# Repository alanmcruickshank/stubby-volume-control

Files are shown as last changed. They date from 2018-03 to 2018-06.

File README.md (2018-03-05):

# stubby-volume-control
A distinctly over engineered USB volume control designed in OpenSCAD and programmed using Arduino

## Contents
- [Design](/scad/design.md)
- [Programming](/cpp/programming.md)
- [Assembly](/docs/assembly.md)

## TODO

- Add all the scad files and some explanation of what they do (a branch for the original version first and then a dev branch for the new version)
- Add a full set of stl files and the tag that as a *release* before changing them all.
- Add some docs around print settings for best results, especially for the geared components. i.e. RAFTS!

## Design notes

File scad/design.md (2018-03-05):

# Design

There are a couple of physical design iterations:

- [_Alpha_](/scad/alpha.md) - the first iteration
- [_Beta_](/scad/beta.md) - a stubby incomplete iteration

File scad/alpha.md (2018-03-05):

# Alpha Design

This design was the first and was created iteratively to get *something that worked*.

It incorporates all the main components that the design requires, but is in no way *optimsed*.

## Important points

- Sanding the interface layers with a really fine grain sandpaper helps for really smooth functionality
- Print the geared components with a raft so that we don't get wierd edge effects which affect binding.

## Pictures

### Complete
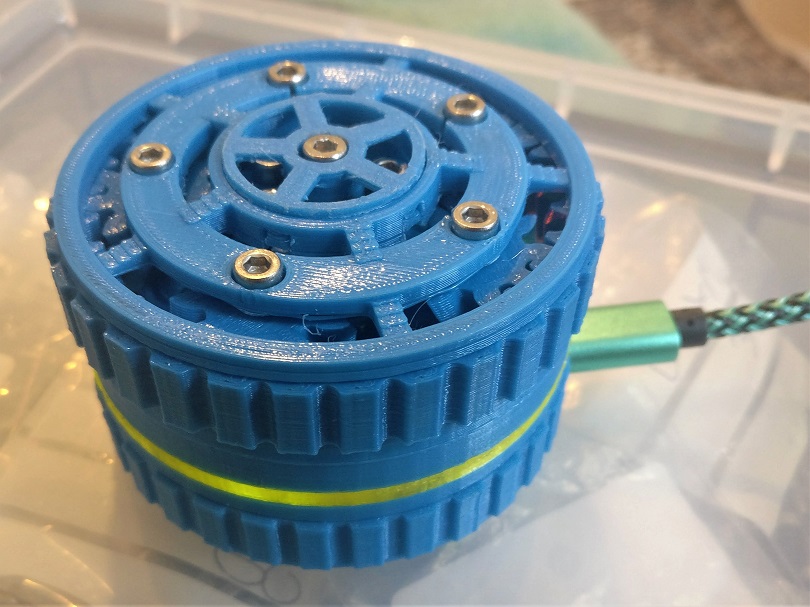
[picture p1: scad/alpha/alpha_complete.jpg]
the complete alpha design


### Upper
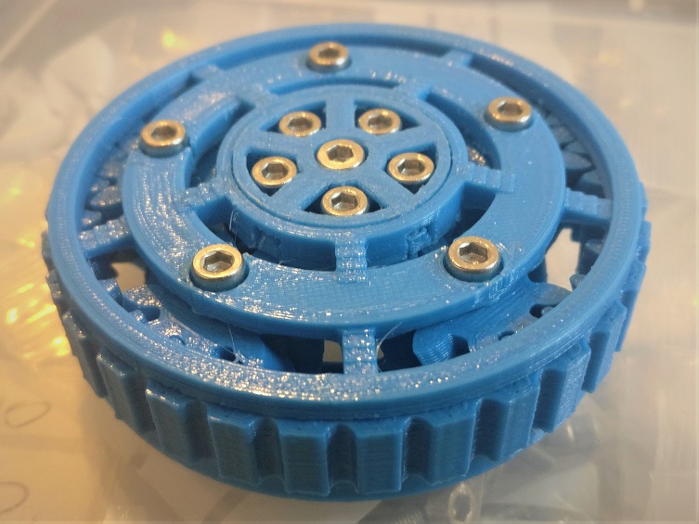
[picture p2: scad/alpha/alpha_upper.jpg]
the upper half of the alpha design


### Lower
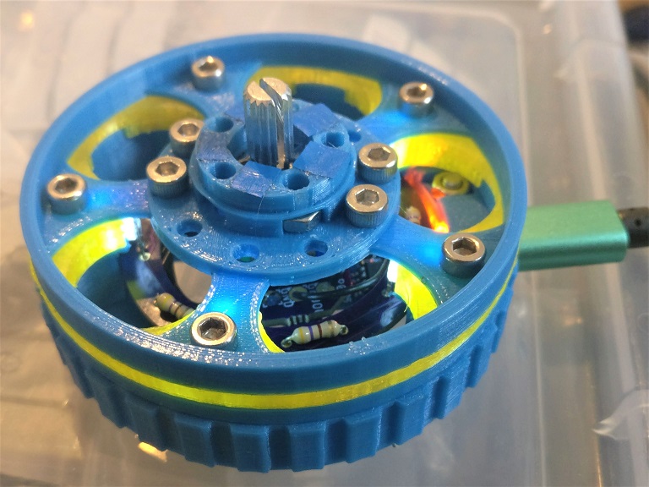
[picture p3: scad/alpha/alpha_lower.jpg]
the lower half of the alpha design


## Good points:

- Design can be assembled as two independant assemblies. The upper **gearbox assembly** and the lower **electronics assembly**. The two are then joined by the five longer central screws.
- The design of the undercarriage is really nice.
- The LED ring works well, although it should probably be centered in the next revision.
- The tolerances work well, and runs very smoothly with only a little post processing. Rafts of the geared components was the right route, and nice thick ones even though this leads to difficulty removing them.
- The height tolerance above the encoder button can be really easily tweeked using tape attached to the top of the central inner encoder mount.

## Bad points:

- It's quite tall! Perhaps just a bit stumpy, and the lower design could be executed better.
- The nuts which join to the longer central joining screws can easily slide out of place. Perhaps an interference fit or some geometry to capture them might be more appropriate for the next design.
- In practice the gearing is actually too low. You have to turn the knob quite a long way for the relevant increase in volume
- You can't just put your finger on the upper rim as that's integrated with the planet gears and not the ring gear, future versions should have the whole top corner be the interface point for a users finger. this should be linked to the external knurling.
- Designing the geared parts with either bevels or chamfers to make it so rafts aren't necessary would make printing much easier.
- The planetary gear carriers (both upper and lower) don't hold the screws very nicely, a thicker lower would hold the nuts better. Ideally printed in such a way that the hexagonal holders are on the upper side to ease printing.
- It's not **obviously** geared - linked to the gear ratio - perhaps a design where the planets are fixed, the outer rign moves and the center turns the encoder could work well. Could also make construction easier. Ideally we need to find a way of statically holding the upper and lower sides of the planet gears for stiffness. It could also mean an off centre encoder??? That could be very cool. An asymmetric planetary system could be fun.
- We've got the arduino interface for all of the multimedia keys. Mute & skip would be useful buttons to also have. Could implement using microswitches, or even better - 3d print a switch??!
- It's quite light, and so doesn't grip very well on the table. Perhaps some legit bearings would make it more weighty.

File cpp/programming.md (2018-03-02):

# Arduino Files

The design uses the [digistump](http://digistump.com/wiki/digispark), although the micro usb version of the standard digistump as [available on aliexpress](https://www.aliexpress.com/item/Mini-ATTINY85-Micro-USB-Development-Board-for-Digispark-Kickstarter/32658933669.html). For this to work in the Arduino environment you need:

- The local Arduino IDE - from [arduino.cc](https://www.arduino.cc/en/Main/Software)
- The relevant digispark drivers for the arduino IDE - instructions [here](http://digistump.com/wiki/digispark/tutorials/connecting).

The USB driver uses (or at least will use) an altered version of the Digispark Keyboard addon, which is part of the [DigistumpArduino library](https://github.com/digistump/DigistumpArduino). The details of how to emulate multimedia keys are inspired by the work done by Adafruit on their [Trinket library](https://github.com/adafruit/Adafruit-Trinket-USB) (most notable the HIDCombo library).

## Loading the firmware

The digistump is programmed directly through the Arduino interface via usb. No additional functionality required. Press *Upload* in the arduino IDE with the right kind of board selected and it should just work. After loading the firmare you may need to unlplug and then reconnect the volume control before it acts as a control properly.

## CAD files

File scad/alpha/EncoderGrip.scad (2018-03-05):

//$fa = 6;
//$fs = 0.4;

encoder_grip();

module encoder_grip(){
    union(){
        difference(){
            union() {
                cylinder(d=10, h=11.5);
            }
            
            // grip the encoder
            cylinder(d=6.4, h=8);
            
            // chamfer for encoder
            cylinder(d1=8, d2=6.45, h=2);
            
            // screw hole
            cylinder(d=3.3, h=14);
            
            // key way
            translate([2.5,-6,11]) cube([12,12,12]);
            translate([-2.5-12,-6,11]) cube([12,12,12]);
            
            // captive nut
            translate([0,0,9]) cube([12,5.5,2.8], center=true);
            translate([0,0,9.5]) cube([3.3,5.5,2.5], center=true);
            
        }

        // encoder keyway
        translate([0,0,3.8]) cube([9,0.6,7.6], center=true);
    }
}

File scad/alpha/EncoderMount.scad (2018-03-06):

$fa = 6;
$fs = 0.4;

// distance of bottom of stator to bottom of grip = 10mm
// encoder fits into grip by 7.6mm

// => 17.6mm of the encoder is above the base of this

// top of encoder is 20mm from bottom of thread

// therefore thickness of 2.4

// thread is M7



difference() {
    union () {
        cylinder(d=34, h=2);
        // higher central mount
        cylinder(d=14, h=3.2);
    }
    
    cylinder(d=7.2, h=8);
    translate([0,0,1.4]) cylinder(d=9, h=8);
    
    //translate([0,-5,1.5]) cube([7, 10, 3], center=true);
    
    for (i=[0:9]) {
        rotate([0,0,(i*36) - 18]) translate([8,0,0]) cylinder(h=8, d=3.4);
    }
    
    for (i=[0,1,5,6]) {
        rotate([0,0,(i*36) - 18]) translate([-14,0,0]) cylinder(h=4, d=3.4);
        rotate([0,0,(i*36) - 18]) translate([-14,0,1]) rotate([0,0,90]) cylinder(d=7, h=4, $fn=6);
        // and again just to cut corners
        rotate([0,0,(i*36) - 18]) translate([-16,0,1]) rotate([0,0,90]) cylinder(d=7, h=4, $fn=6);
    }
    
    // cut the shape
    translate([-40,7,0]) cube([80,10,4]);
    mirror([0,1,0]) translate([-40,7,0]) cube([80,10,4]);
    
}

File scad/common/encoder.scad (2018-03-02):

// Standard encoder dimensions
$fa = 6;
$fs = 0.4;

translate([0,60,0]) encoder_and_board();

translate([60,60,0]) encoder();

translate([-60,60,0]) encoder_board();

module encoder_and_board(){
    union(){
        encoder();
        translate([0,0,-7-3.8]) encoder_board(); 
    } 
}

module encoder_board(){
    translate([-14.2,-9.7,0]) cube([28.4,19.4,3.8]);    
}

module encoder(){
    difference(){
        union(){
            cylinder(d=7, h=7);
            cylinder(d=4, h=16);
            translate([0,0,10]) cylinder(d=6, h=10);
            translate([-6,-6,-7]) cube([12,12,7]);
        }
        // Keyway slot
        translate([0,0,20-5.5]) cube([1,12,11], center=true);  
    }
}

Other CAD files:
scad/alphaAssembly.scad
scad/alpha/BasePlate.scad
scad/alpha/CentreButton.scad
scad/alpha/ElectroHousing.scad
scad/alpha/GearCarrier.scad
scad/alpha/Gears.scad
scad/alpha/LightRing.scad
scad/alpha/LightRingSpacer.scad
scad/alpha/UnderCarrier.scad
scad/alpha/UnderStator.scad
scad/common/fixings.scad

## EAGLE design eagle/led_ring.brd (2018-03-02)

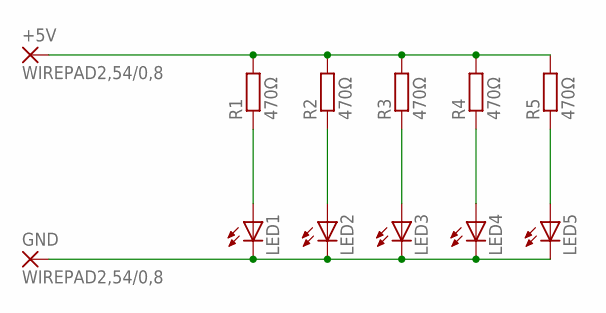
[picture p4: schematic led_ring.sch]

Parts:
+5V: WIREPAD2,54/0,8; 2,54/0,8
GND: WIREPAD2,54/0,8; 2,54/0,8
LED1, LED2, LED3, LED4, LED5: LED5MM
R1, R2, R3, R4, R5: 470Ω; 0204/7

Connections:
unnamed: LED1.A, R1.1
unnamed: LED2.A, R2.1
unnamed: LED3.A, R3.1
unnamed: LED4.A, R4.1
unnamed: LED5.A, R5.1
unnamed: +5V.1, R1.2, R2.2, R3.2, R4.2, R5.2
unnamed: GND.1, LED1.K (C), LED2.K (C), LED3.K (C), LED4.K (C), LED5.K (C)

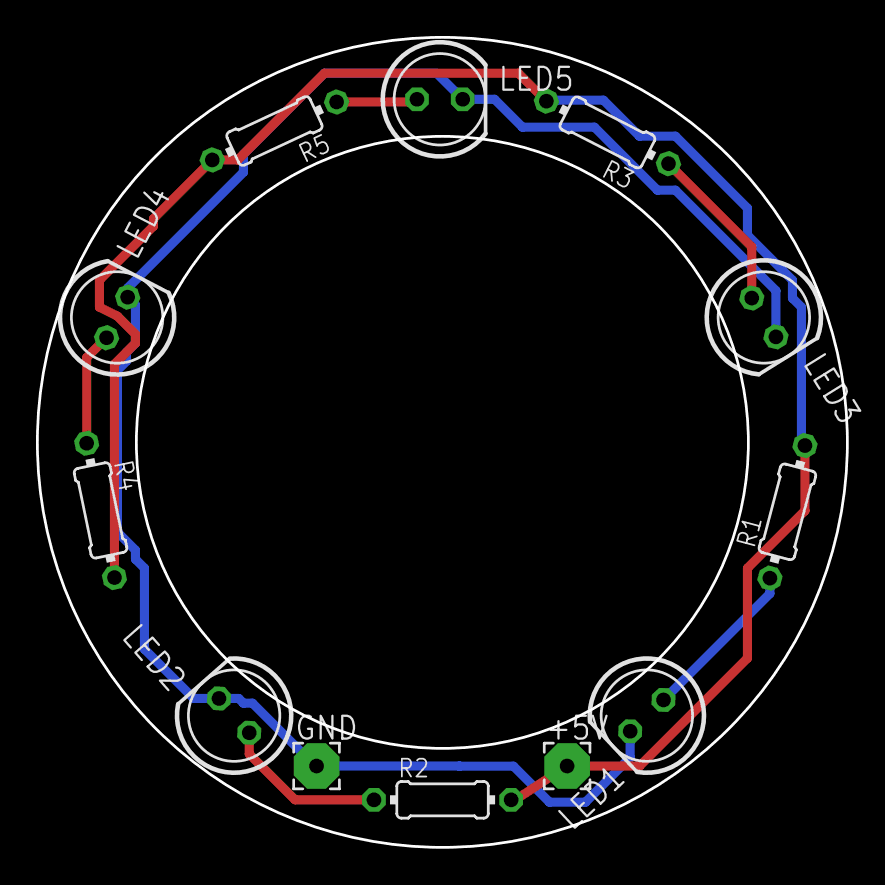
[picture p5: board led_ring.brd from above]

Board: 2 copper layers, 45.0 x 45.0 mm, 12 parts (0 on the bottom side), 7 nets.

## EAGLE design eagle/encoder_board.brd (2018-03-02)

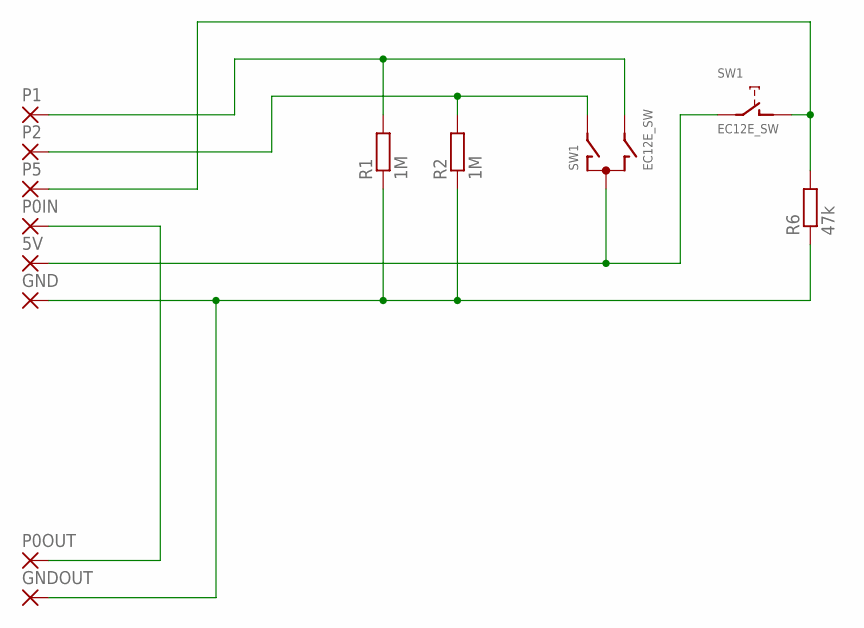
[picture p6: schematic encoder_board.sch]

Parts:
5V: 2,54/0,8
GND: 2,54/0,8
GNDOUT: 2,54/0,8
P0IN, P0OUT, P1, P2, P5: 2,54/0,8
R1, R2: 1M; 0204/7
R6: 47k; 0204/7
SW1: EC12E_SW; ALPS_EC12E_SW

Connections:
GND2: GND.1, GNDOUT.1, R1.1, R2.1, R6.1
unnamed: P0IN.1, P0OUT.1
unnamed: P5.1, R6.2, SW1.D (1)
unnamed: P2.1, R2.2, SW1.A
unnamed: P1.1, R1.2, SW1.B
unnamed: 5V.1, SW1.C, SW1.E (2)

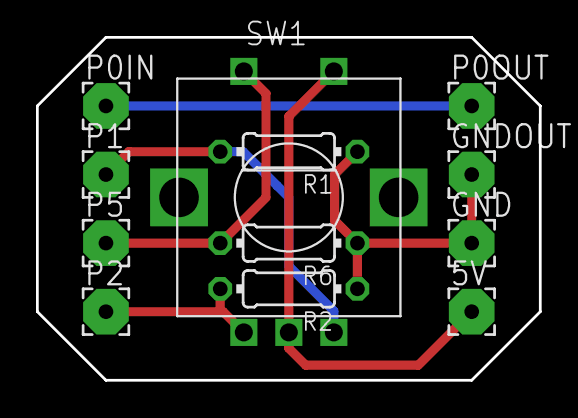
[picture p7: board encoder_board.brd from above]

Board: 2 copper layers, 27.9 x 19.1 mm, 12 parts (0 on the bottom side), 6 nets.

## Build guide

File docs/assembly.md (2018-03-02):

# Assembly Instructions

**TODO:** Write down how to assemble the damn thing

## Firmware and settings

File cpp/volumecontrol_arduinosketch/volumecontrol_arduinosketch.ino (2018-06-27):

#include "TrinketHidCombo.h"
// Get the TrinketHidCombo from here: https://github.com/adafruit/Adafruit-Trinket-USB/tree/master/TrinketHidCombo

#define ENCODER_PIN_A         2
#define ENCODER_PIN_B         1
#define LED_PIN               0
#define BUTTON_PIN            5

#define SPIN_LED_IMPULSE      24
#define STEADY_LED_LEVEL      52
#define PLAYPAUSE_LED_LEVEL   220
// Initial LED level
#define INIT_LED_LEVEL        0
// This is the timeout to move the LED level by 1
#define LED_REVERT_TIMEOUT    28
// This is the timeout to move the LED level by 1 (when in bump mode)
#define BUMP_LED_REVERT_TIMEOUT    2
#define DISCONN_LIMIT         200
// The point at which pin five should be considered to be pulled low
#define PIN_5_ANALOGUE_LIMIT  950

// define some signal values
// values below are read from right to left
// CLOCKWISE = 231 = 0AABB0 = 011110 = 30
// ANTI = 132 = B0AB0A = 101101 = 45
#define EVENT_CLOCKWISE_TURN  0b011110 //30
#define EVENT_ANTICLOCK_TURN  0b101101 //45

byte led_set_point = 0;
byte out_d = INIT_LED_LEVEL;
// initialise the first time at which we start to revert the LED to zero so we force an update as soon as we're running
unsigned long bookmark_time = 0;
// initialise the buffer to keep track of track skipping (needs to be negative safe) (char is a signed 8 bit integer)
char track_skip = 0;
byte disconn_counter = 0;
byte bump_target = 0;
bool bump_active = false;

// Using bit shifting for the buffer.
// Encoder buffer is two bits at a time
// Button buffer is one bit at a time
// Initialise the state buffers to zero
byte encoder_state_buffer = 0b0;
byte button_state_buffer = 0b0; 

// the setup routine runs once when you press reset:
void setup() {
    // initialize the digital pin as an output.
    pinMode(LED_PIN, OUTPUT); // LED Output
    pinMode(ENCODER_PIN_A, INPUT); // Encoder Pin 1
    pinMode(ENCODER_PIN_B, INPUT); // Encoder Pin 2
    pinMode(BUTTON_PIN, INPUT); // Pause Button
}

/* Read the current encoder state from the relevant pins */
byte read_encoder_state(){
    // Read the pins
    byte a = digitalRead(ENCODER_PIN_A);
    byte b = digitalRead(ENCODER_PIN_B);
    // state is a number between 0 and 3, upper bit is pin 2, lower is pin 1
    // 0 = 00
    // 1 = 0A
    // 2 = B0
    // 3 = AB
    return a + (b << 1);
}

/* Read the button state from the relevant pins */
byte read_button_state(){
    // pin 5 is the reset button so we can't pull it low, but we can pull it higher!
    // also pin 5 is analogue read 0 (wierd eh??)
    // check threshold of m_analogue and set to 1 if over 950 else 0
    byte m = analogRead(0) > PIN_5_ANALOGUE_LIMIT;
    // analogue read returns a number between 0 and 1023, it's not 8 bit but the result of the comparison is.
    return m;
}

/* change the current val by up to the increment without going past the bounds */
byte capped_move(byte current_val, char increment){
    // Use an int here because then we can go past the bounds
    int val_buffer = current_val;
    return constrain(val_buffer + increment, 0, 255);
}

/* reset the led timer */
void reset_led_timer(){
    if (bump_active) {
        bookmark_time = millis() + BUMP_LED_REVERT_TIMEOUT;
    } else {
        bookmark_time = millis() + LED_REVERT_TIMEOUT;
    }
}

/* use the led bump functionality to bump the brightness more nicely */
void bump_output_to(byte target){
    // bump the LED output to a given level
    bump_target = target;
    bump_active = true;
    reset_led_timer();
}

// the loop routine runs over and over again forever:
void loop() {
    // Get input states
    byte encoder_state = read_encoder_state();
    byte button_state = read_button_state();
    bool state_change = false;

    // ################## Case 1
    // Filter encoder buffer to see if it's changed (3 = 00000011 so masks to just the first two bits)
    // brackets are important because == evaluates before &
    if ((encoder_state_buffer & 0b11) != encoder_state) {
        // update the buffer
        encoder_state_buffer = (encoder_state_buffer << 2) + encoder_state;
        // detect turns of the encoder
        if ((encoder_state_buffer & 0b111111) == EVENT_CLOCKWISE_TURN) {
            // if we can add the impulse without wraparound, then do so, otherwise cap
            bump_output_to(capped_move(out_d, SPIN_LED_IMPULSE));
            if (button_state) {
                // if the button is pressed then skip forward
                TrinketHidCombo.pressMultimediaKey(MMKEY_SCAN_NEXT_TRACK);
                track_skip++;
            } else {
                // if the button is not pressed then vol up
                TrinketHidCombo.pressMultimediaKey(MMKEY_VOL_UP);
            }
        } else if ((encoder_state_buffer & 0b111111) == EVENT_ANTICLOCK_TURN) {
            // if we can take the impulse without wraparound, then do so, otherwise cap
            bump_output_to(capped_move(out_d, -SPIN_LED_IMPULSE));
            if (button_state) {
                // if the button is pressed then skip forward
                TrinketHidCombo.pressMultimediaKey(MMKEY_SCAN_PREV_TRACK);
                track_skip--;
            } else {
                // if the button is not pressed then vol up
                TrinketHidCombo.pressMultimediaKey(MMKEY_VOL_DOWN);
            }
        }
    }
    // ################## Case 2
    // Filter butten buffer to see if it's changed (1 = 00000001 so masks to just the first bit)
    else if ((button_state_buffer & 0b1) != button_state) {
        button_state_buffer = (button_state_buffer << 1) + button_state;
        // is it a push or a release?
        if (button_state) {
            // push
            // ... so boost the led and reset track skip
            bump_output_to(PLAYPAUSE_LED_LEVEL);
            // reset the track buffer
            track_skip = 0;
        } else if (track_skip == 0) {
            // release (and no track skipping) - so trigger a play/pause
            TrinketHidCombo.pressMultimediaKey(MMKEY_PLAYPAUSE);
        }
        // delay a little to debounce
        delay(2);
    }
    // ################## Case 3
    else if (millis() > bookmark_time) {
        // No state change of buttons and the timeout on the fading has been reached
        if (bump_active) {
            if (out_d < bump_target) {
                out_d += 1;
            } else if (out_d > bump_target) {
                out_d -= 1;
            } else {
                bump_active = false;
            }
        } else {
            if (out_d < led_set_point) {
                out_d += 1;
            } else if (out_d > led_set_point) {
                out_d -= 1;
            }
        }
        // reset timer
        reset_led_timer();
        // write the value
        analogWrite(LED_PIN, out_d);
        // Check for disconnect
        if (TrinketHidCombo.isConnected()){
            // We're connected so make sure that the lights are on.
            led_set_point = STEADY_LED_LEVEL;
            // We're connected so reset the counter and poll
            disconn_counter = 0;   
        } else {
            // Increment the disconnect counter (to count the cycles we're disconnected
            // NB: this is cycles within the bookmark loop - so it's a slower loop than the main loop
            disconn_counter += 1;
            // Set the LED target intensity to zero (we're disconnected)
            led_set_point = 0;
            // Check if we've been disconnected long enough to warrant a reconnect
            if (disconn_counter > DISCONN_LIMIT) {
                // Force re-enumeration
                TrinketHidCombo.begin();
                // Reset counter so that we don't try too often
                disconn_counter = 0;
                // Delay a little (100ms) post-reconnection to give things time to reassert themselves
                delay(100);
            }
        }
        // Send a polling stroke to remind the machine we're here (given we're already connected)
        TrinketHidCombo.poll(); // do nothing, check if USB needs anything done  
        //NB: Polling even when not yet connected - forces the connection to initiate after a .begin() command
    }
}

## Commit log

2018-03-02 Basic docs and a todo - adding a framework before transititioning things over into the git repo
2018-03-02 A version of the arduino sketch with *does* compile, but the multimedia keys aren't working. Need work on porting some more of the trinket library across.
2018-03-02 Adding and cleaning the first stages of the alpha model
    [CentreButton.scad, GearCarrier.scad, Gears.scad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]
2018-03-02 Add Eagle files
    [encoder_board.brd, encoder_board.sch, led_ring.brd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]
2018-03-03 Arduino code works again!
2018-03-05 Finish the upper gearbox assembly in scad and add in some pictures.
    [CentreButton.scad, EncoderGrip.scad, alphaAssembly.scad]
2018-03-06 add the rest of the lower assembly (ex boards at the moment)
    [BasePlate.scad, ElectroHousing.scad, EncoderMount.scad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]
2018-06-01 Upgrade firmware to allow skip forward and backward while button is pressed. Only play or pause on button up (rather than down) and only if no tracks skipped.
    [volumecontrol_arduinosketch.ino]
2018-06-18 a little bit of disconnect logic as a trial to see whether it fixes the disconnect issue
    [volumecontrol_arduinosketch.ino]
2018-06-19 Refactor of firmware to fix the issue of not connecting until a button pressed. Also added the bump brightness feature so that brightness is a bit smoother.
    [volumecontrol_arduinosketch.ino]
